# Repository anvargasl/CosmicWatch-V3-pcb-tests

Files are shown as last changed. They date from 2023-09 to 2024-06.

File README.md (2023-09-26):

# CosmicWatch_V3_RP

Handling versions of CosmicWatch pcb design, reusing V2 DC to DC booster and implementing new peak detection designa.

## CosmicWatch_detector_v30

main project, bringing together the different versions of parts desinged for peak detection and power.

### DC-DC-booster

Reimplementing CosmicWatch-V2 Dc to DC booster for lower noise in the power line.

### Peak-Detector

Latest peak detector circuit implemented for tests.

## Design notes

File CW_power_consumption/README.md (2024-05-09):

This folder contains some measurements made (current and tension) to test the power consumption of CosmicWatch while collecting data for gamma spectroscopy, all this while displaying data on the OLED screen, flashing the LED for every event, and recording temperature and preassure with the BMP280 sensor.

### CW_booting.csv

Power consumption data while initiating the detector.

### CW_high_count_rate.csv

Power consumption data while measuring a high count rate (next to a 54Mn source with 0.612 Mbq activity).

### CW_normal_working_conditions.csv

Power consumption data while measuring only background radiation from the enviroment and self-absorption of a 4x4x22 mm cubed LYSO crystal.

### CW_power_consumption.set

Contains the setup data for the Keithley Series 2280S High Precision Bench Power Supply used to measure current and tension.

### CW_power_measurements.txt

Shows some of the data collected by the CosmicWatch while testing its power consumption.

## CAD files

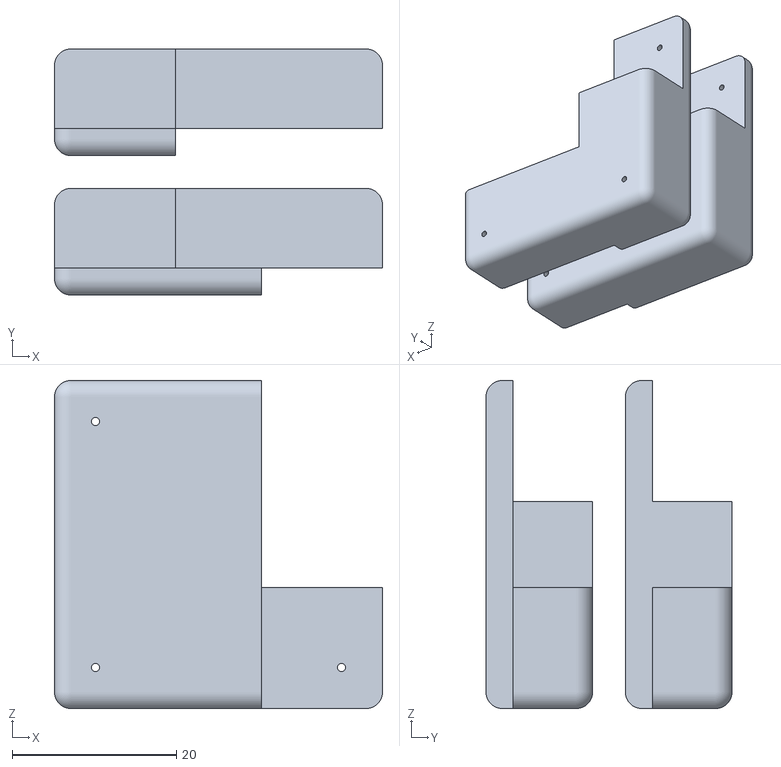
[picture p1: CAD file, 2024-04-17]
3D-print/BGO-10x10x10-holder.stl
40.0 x 30.0 x 40.0

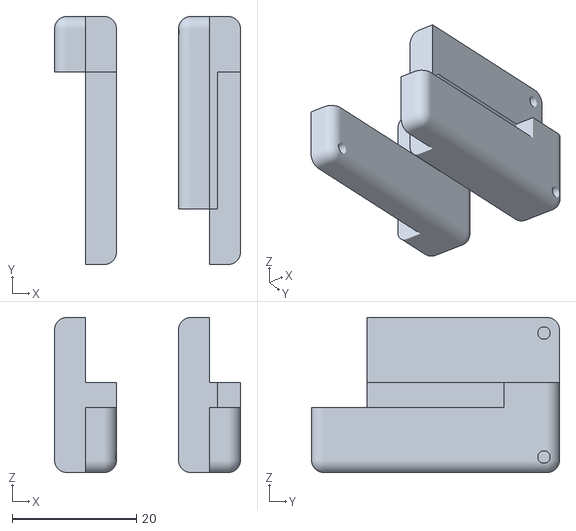
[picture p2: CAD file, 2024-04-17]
3D-print/LYSO-4x4x22-holder-T-pcb.stl
30.0 x 40.0 x 25.0

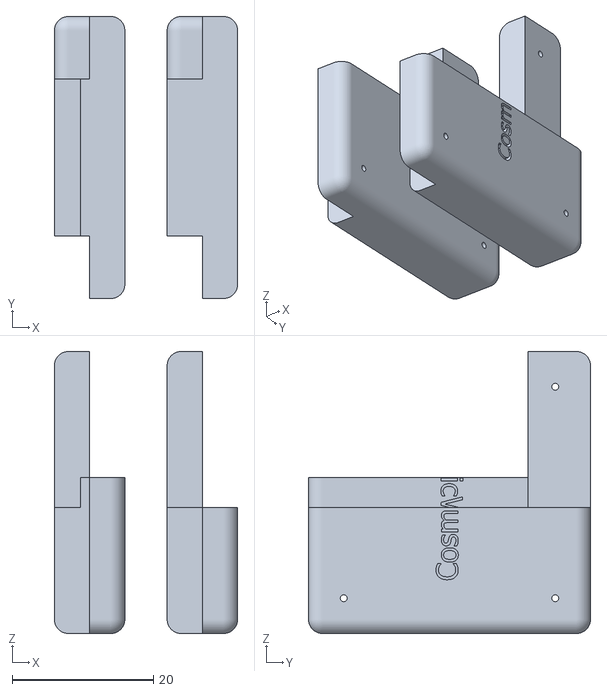
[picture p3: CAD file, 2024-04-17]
3D-print/LYSO-4x4x22-holder.stl
26.0 x 40.0 x 40.0

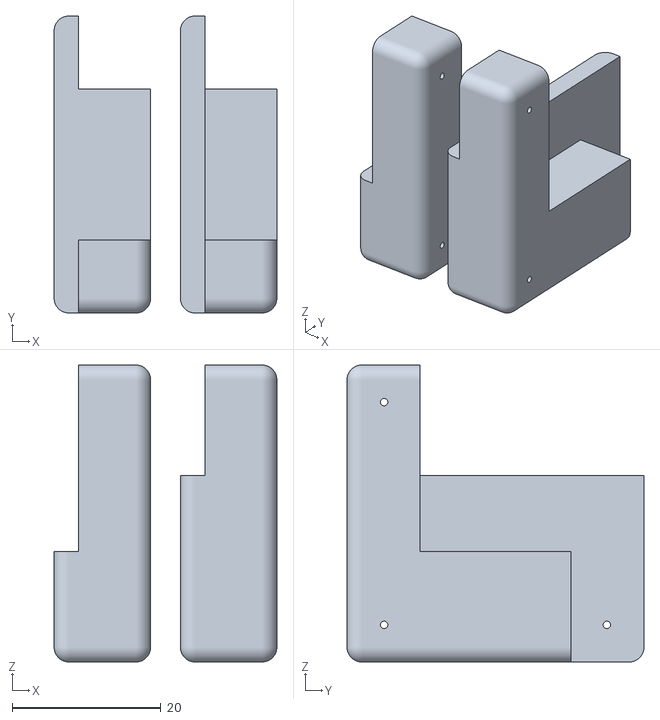
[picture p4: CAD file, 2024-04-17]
3D-print/BGO-10x10x20-holder.stl
30.0 x 40.0 x 40.0

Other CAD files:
3D-print/BGO-10x10x10-holder.ipt
3D-print/BGO-10x10x20-holder.ipt
3D-print/LYSO-4x4x22-holder-T-pcb.ipt
3D-print/LYSO-4x4x22-holder.ipt
3D-print/OldVersions/BGO-10x10x10-holder.0006.ipt
3D-print/OldVersions/BGO-10x10x20-holder.0004.ipt
3D-print/OldVersions/LYSO-4x4x22-holder-T-pcb.0002.ipt
3D-print/OldVersions/LYSO-4x4x22-holder.0024.ipt
3D-print/OldVersions/LYSO-holder-C-conector.0023.ipt
3D-print/OldVersions/LYSO-holder-V3.0001.ipt
3D-print/middle.ipt
3D-print/top-big.ipt
3D-print/top-small.ipt

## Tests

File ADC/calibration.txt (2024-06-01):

pulse_val,e_count,t0[us],dt0[us],readings
12,1,8297765,98,5425,5217,5425,5121,5537
12,2,8299051,91,5169,5569,5313,5089,5505
12,3,8300128,91,5217,5377,5313,5409,5473
12,4,8301174,88,5441,5073,5553,5281,5073
12,5,8302213,87,5185,5521,5377,5137,5569
12,6,8303245,92,5457,5089,5585,5313,5153
12,7,8304281,95,5361,5473,5169,5441,5121
12,8,8305327,92,5521,5105,5537,5377,5105
12,9,8306371,90,5345,5169,5457,5057,5425
12,10,8307419,89,5457,5089,5505,5377,5105
12,11,8308468,88,5329,5345,5105,5393,5553
12,12,8309514,92,5345,5297,5153,5505,5297
12,13,8316044,91,5409,4913,5393,5377,5025
12,14,8317162,88,5249,5377,5329,5073,5441
12,15,8318215,89,5537,5345,5025,5281,5537
12,16,8319274,87,5217,5329,5281,5185,5521
12,17,8320310,88,5073,5505,5377,5409,5313
12,18,8321342,87,5313,5377,5345,5281,5409
12,19,8322383,85,5505,5121,5313,5345,5265
12,20,8323415,85,5425,5025,5521,5281,5329
12,21,8324467,87,5345,5089,5537,5457,5009
12,22,8325507,87,5553,5137,5537,5441,5073
12,23,8326550,91,5473,5121,5553,5361,5121
12,24,8327579,88,5393,5089,5521,5217,5377
12,25,8334145,95,5329,5009,5425,5377,5089
12,26,8335256,88,5553,5025,5457,5361,4977
12,27,8336312,86,5441,5281,5313,5041,5393
12,28,8337352,86,5409,5009,5393,5297,4993
12,29,8338394,86,5169,5425,4993,5473,5137
12,30,8339427,92,5041,5553,5057,5393,5409
12,31,8340474,91,5537,5425,5217,5409,5201
12,32,8341520,88,5313,5265,5233,5377,5057
12,33,8342566,91,5393,5281,5313,5201,5425
12,34,8343604,89,5217,5377,5553,5009,5409
12,35,8344631,97,5089,5537,5169,5537,5345
12,36,8345696,87,5249,5297,5425,5153,5425
12,37,8352269,92,5441,5217,5105,5521,5153
12,38,8353378,92,5377,5201,5505,5041,5313
12,39,8354436,94,5201,5393,5073,5297,5345
12,40,8355483,87,5505,5041,5249,5649,5153
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

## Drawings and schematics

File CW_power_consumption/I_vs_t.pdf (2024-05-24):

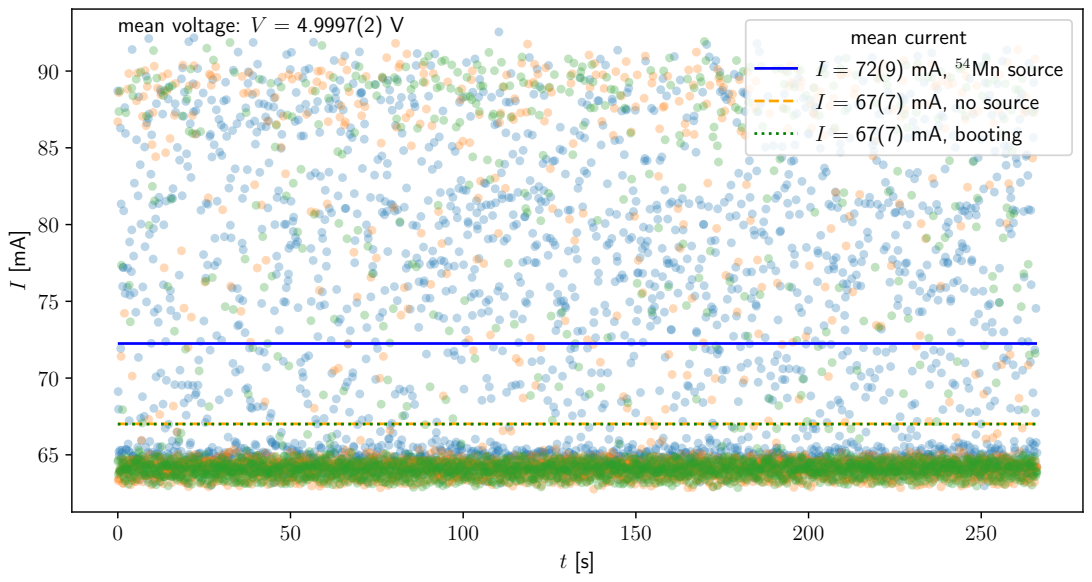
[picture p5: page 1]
mean voltage: V = 4.9997(2) V; mean current

I = 72(9) mA, 54Mn source
I = 67(7) mA, no source
I = 67(7) mA, booting

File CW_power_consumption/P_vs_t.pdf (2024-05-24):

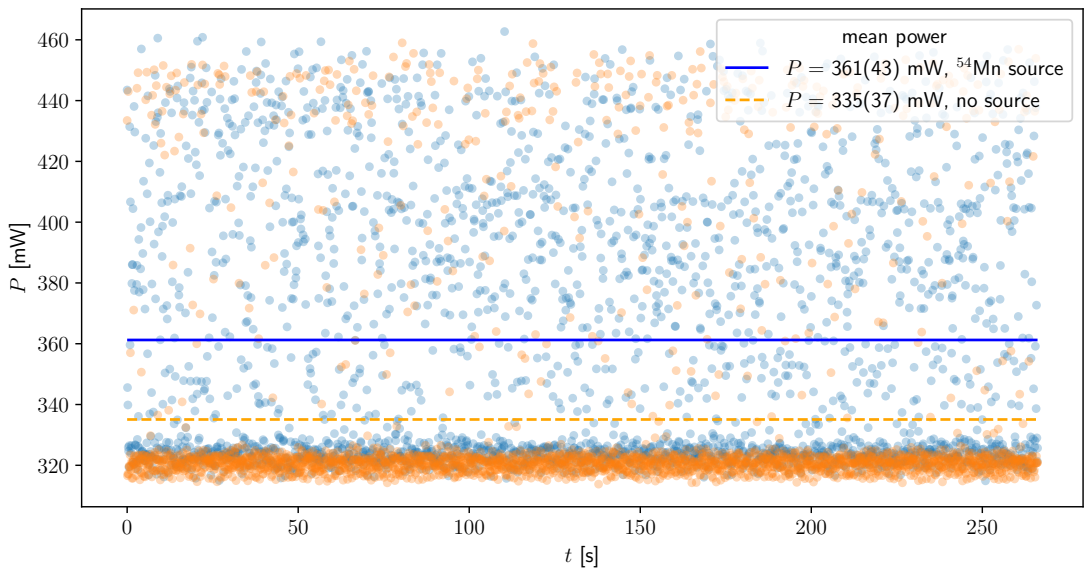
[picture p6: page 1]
mean power; = 361(43) mW, 54Mn source; = 335(37) mW, no source

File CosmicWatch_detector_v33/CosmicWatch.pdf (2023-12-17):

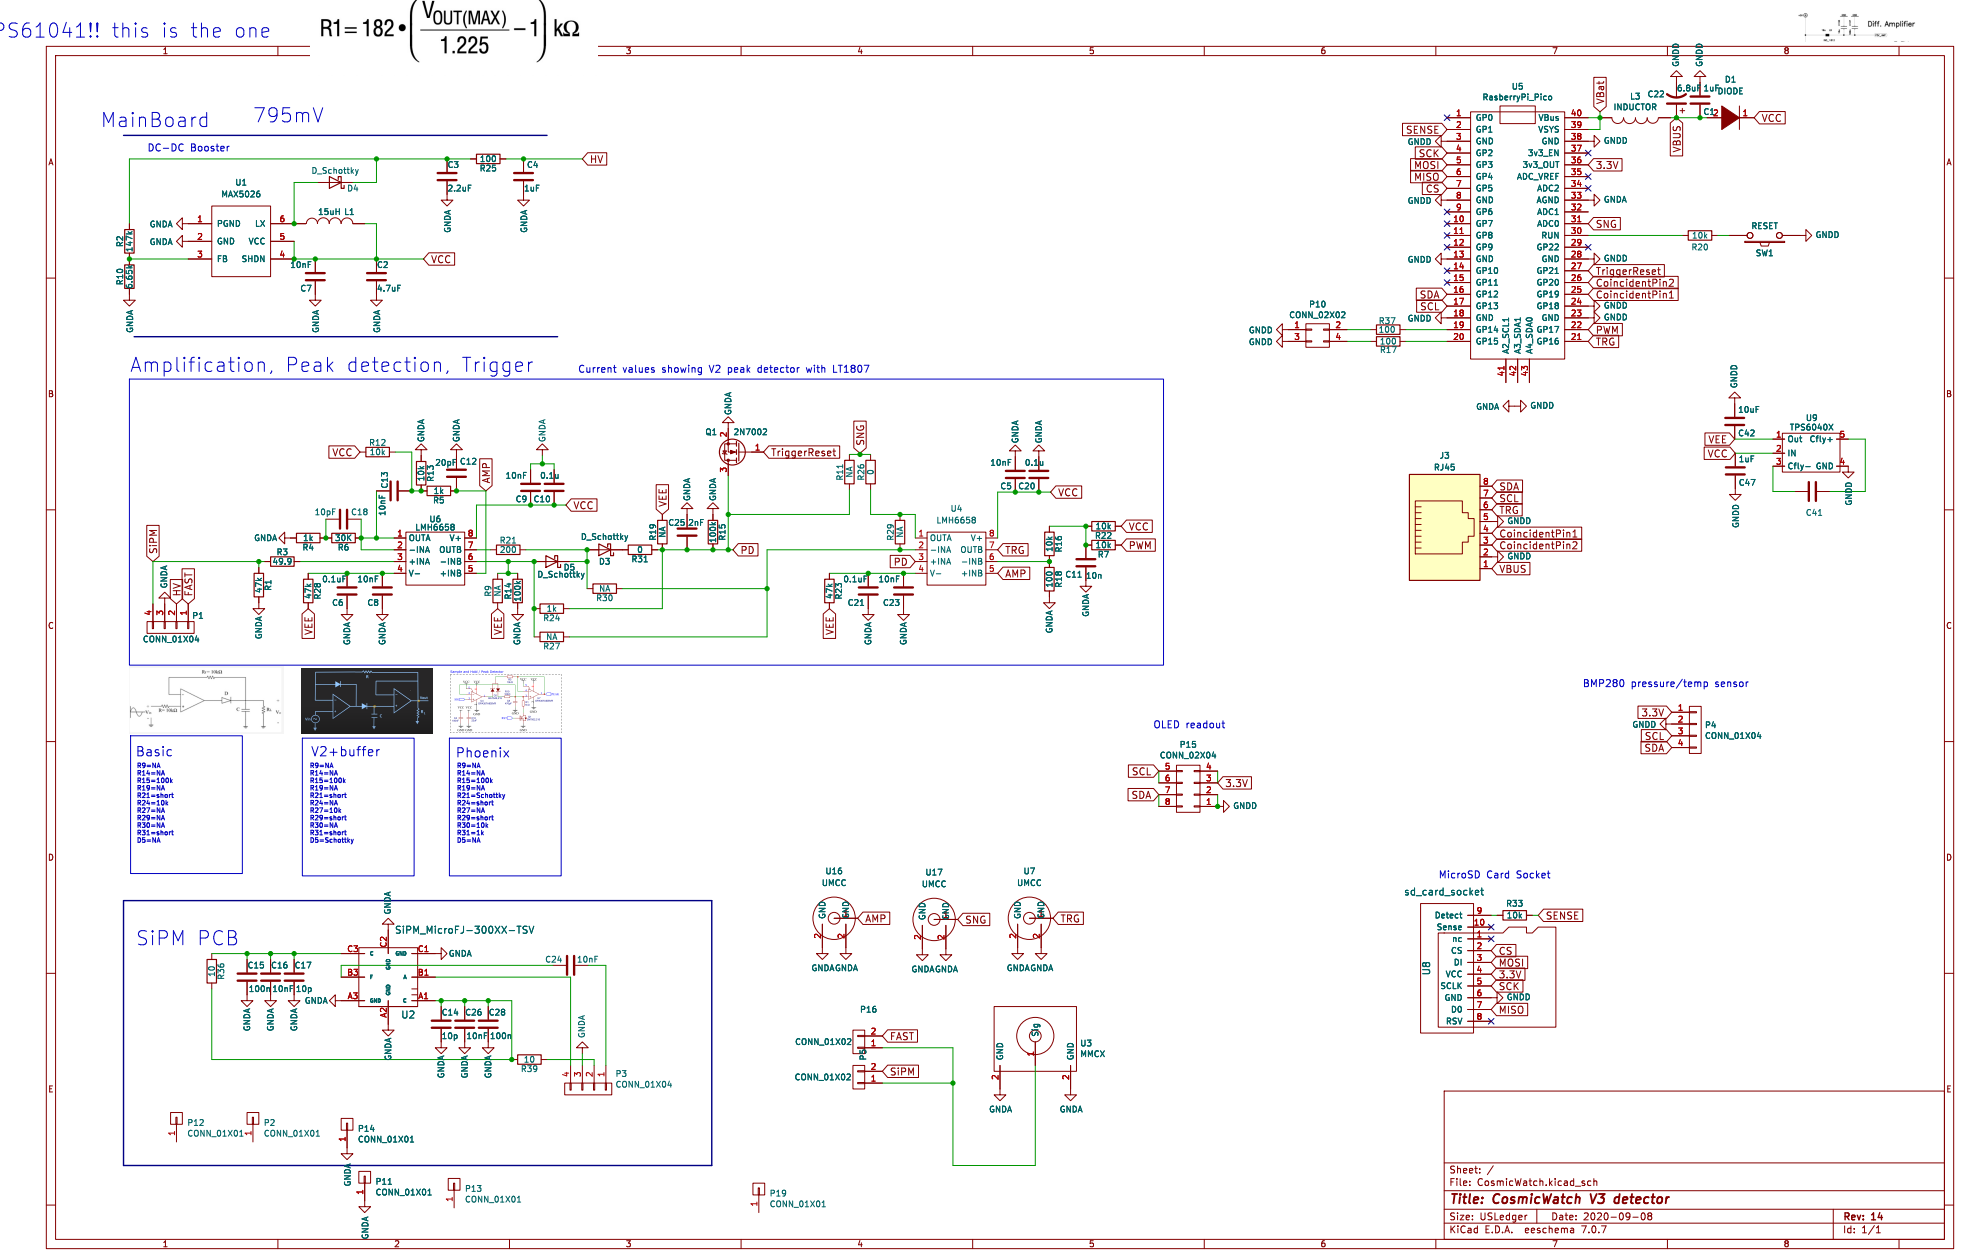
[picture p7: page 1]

1 P13 CONN_01X01 GNDA GNDA GNDA GNDA GNDA GNDA

2 U16 UMCC GNDA GNDA GNDA C7

R9=NA R14=NA R15=100k R19=NA R21=Schottky R24=short R27=NA R29=short R30=10k R31=1k D5=NA R9=NA R14=NA R15=100k R19=NA R21=short R24=NA R27=10k R29=short R30=NA R31=short D5=Schottky R9=NA R14=NA R15=100k R19=NA R21=short R24=10k R27=NA R29=NA R30=NA R31=short D5=NA Basic

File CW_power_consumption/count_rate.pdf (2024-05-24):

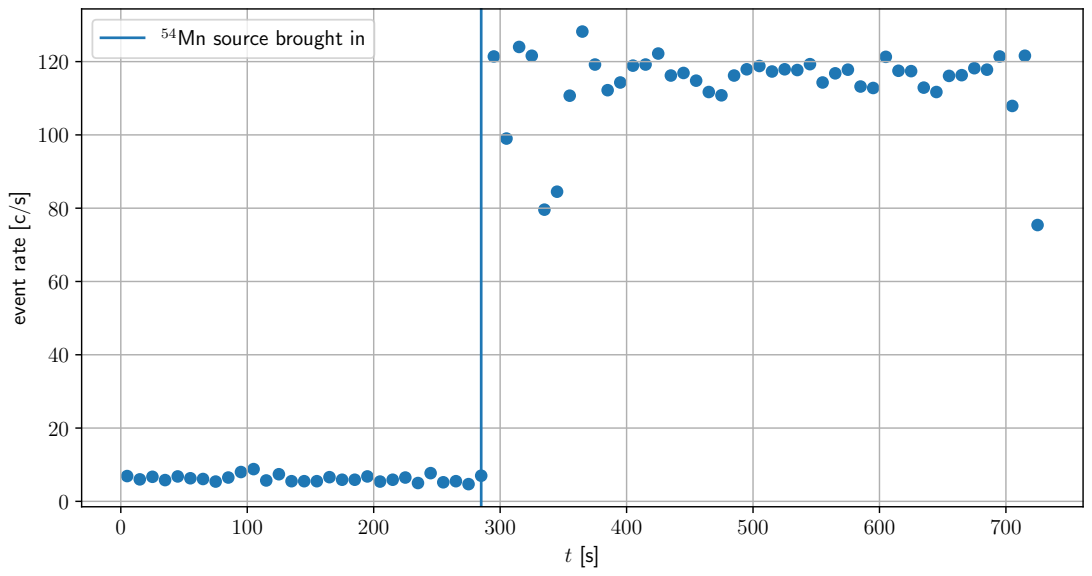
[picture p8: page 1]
event rate [c/s]

54Mn source brought in

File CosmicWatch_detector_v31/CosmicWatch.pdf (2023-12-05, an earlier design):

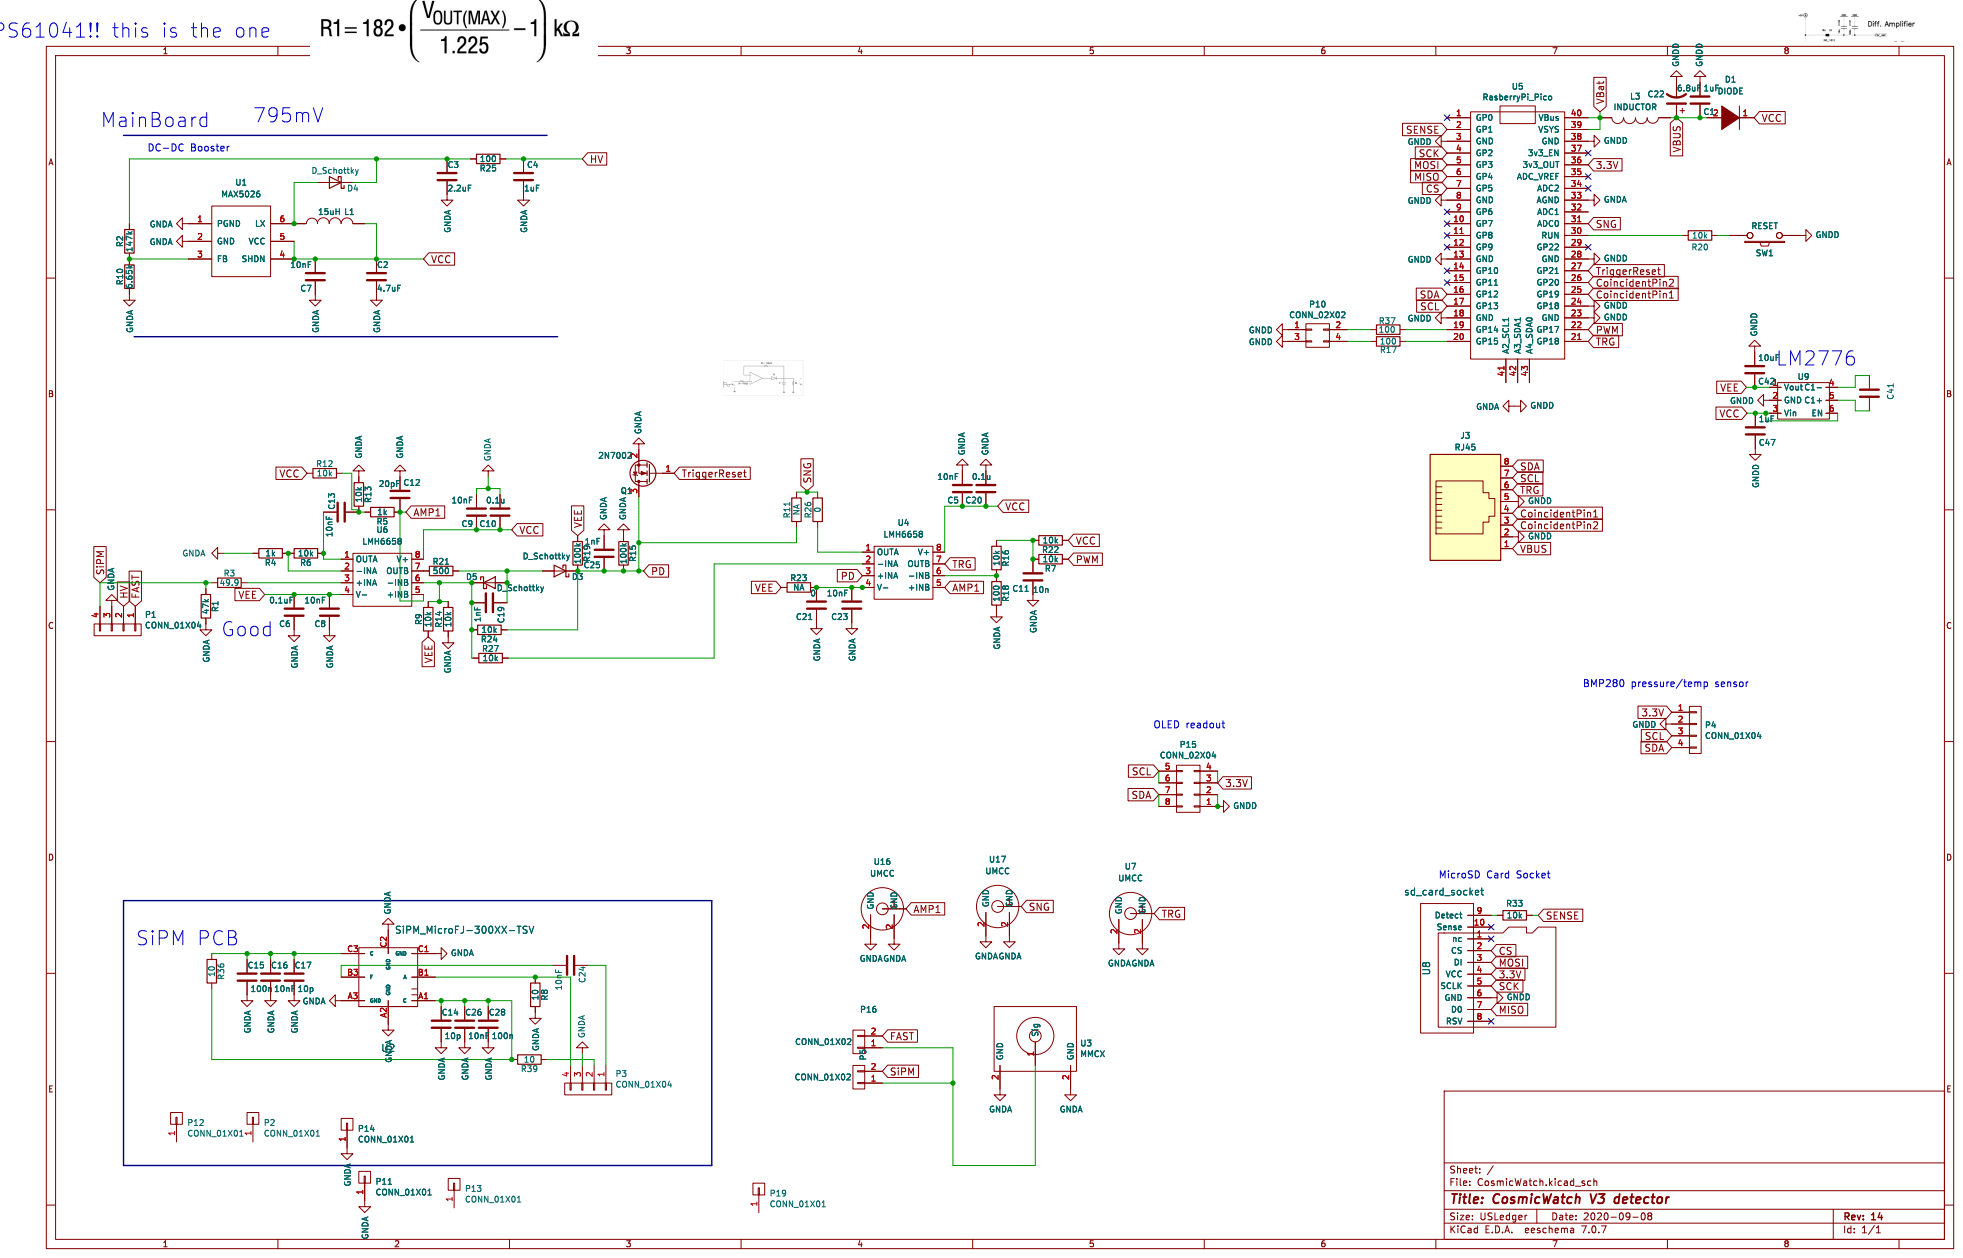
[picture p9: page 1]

OLED readout TPS61041!! this is the one

1P3CONN_01X04 C24 10nF GNDA R2 147k R10 6.65k GNDA GNDA GNDA

2 U16 UMCC GNDA GNDAGNDA Sig

2 GNDA GNDAGNDA U16 UMCC GND 1

Id: 1/1 Title: CosmicWatch V3 detector File: CosmicWatch.kicad_sch Sheet: /

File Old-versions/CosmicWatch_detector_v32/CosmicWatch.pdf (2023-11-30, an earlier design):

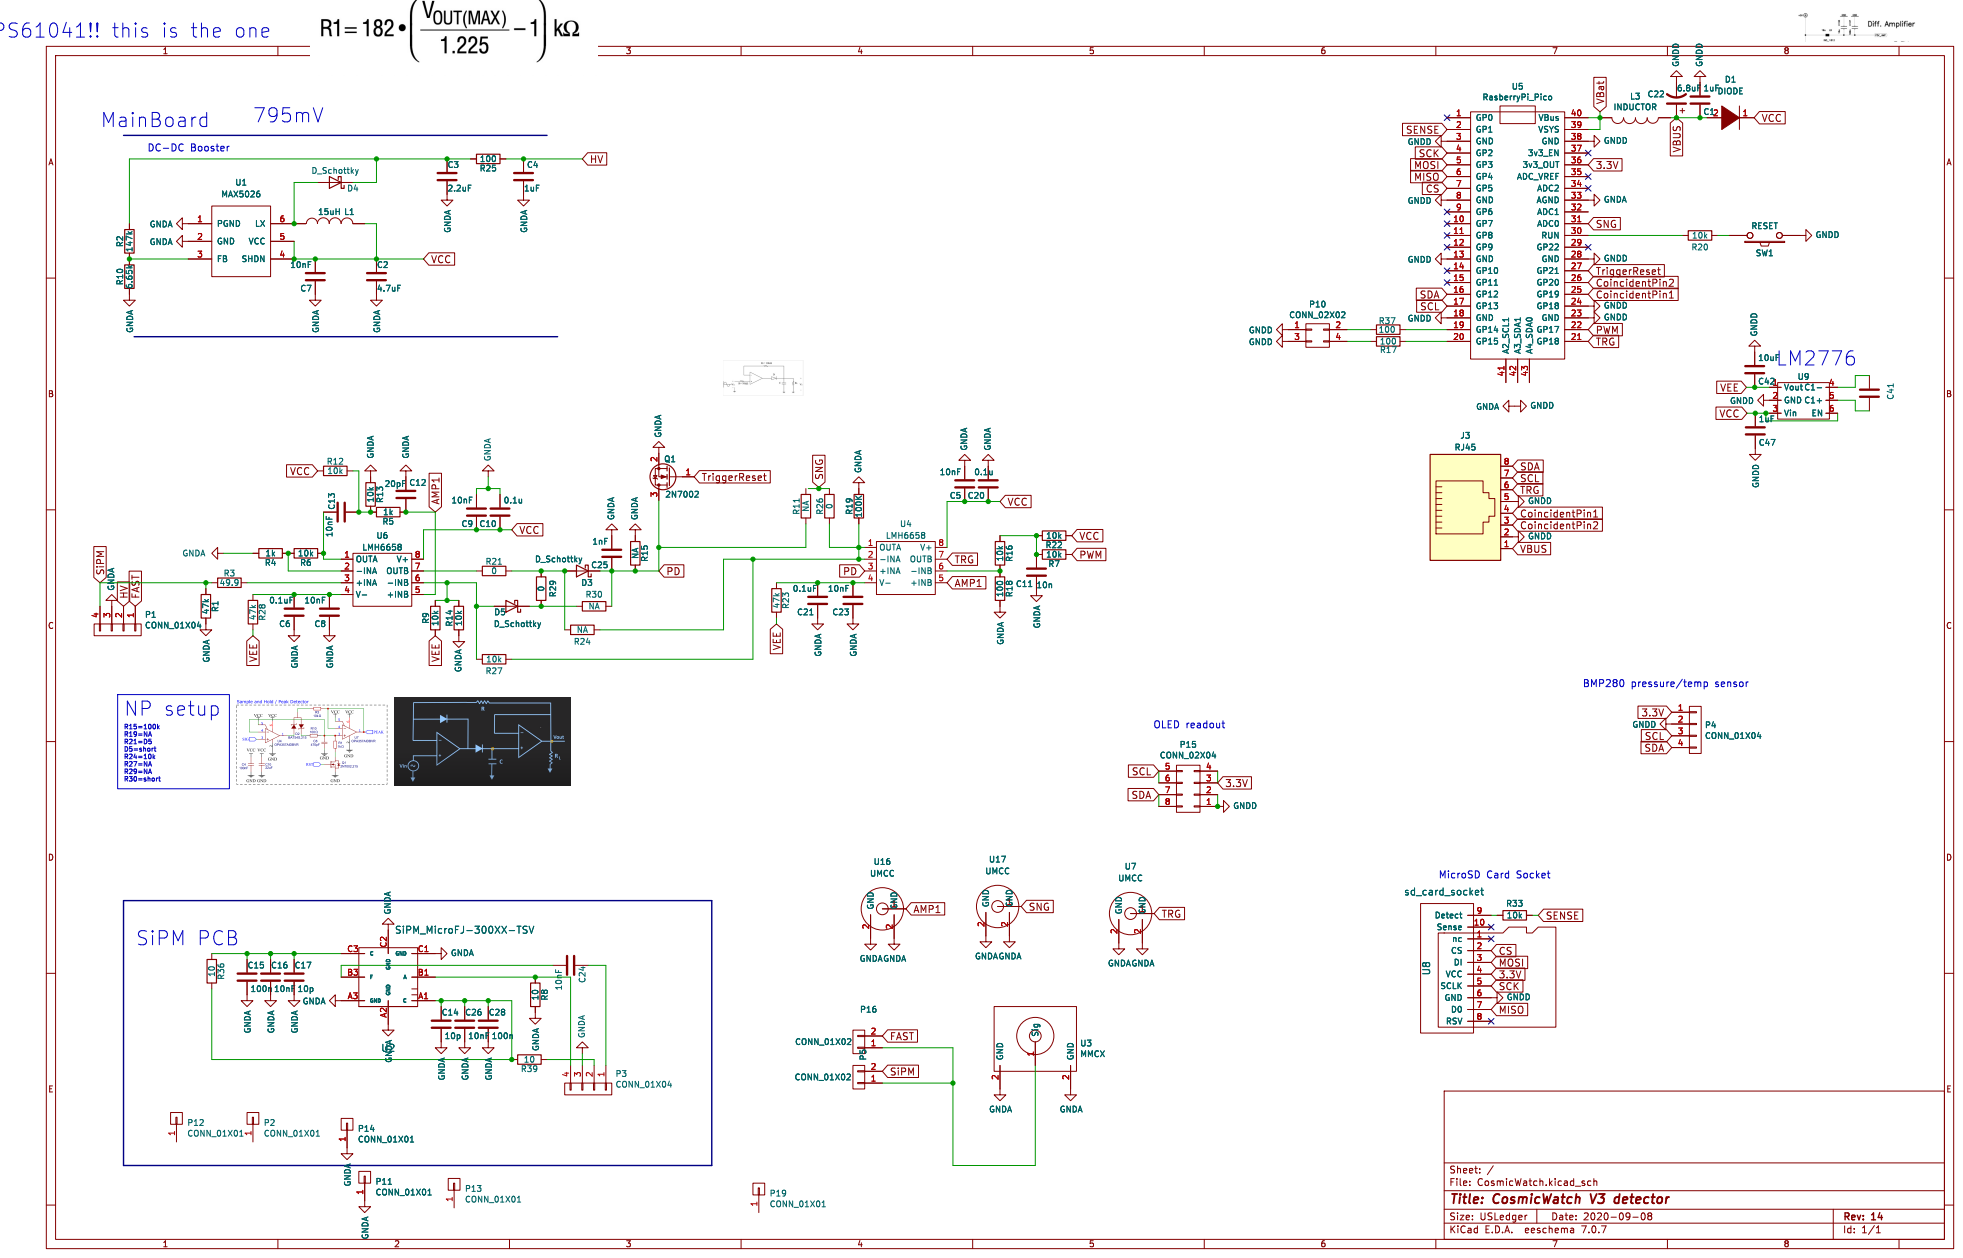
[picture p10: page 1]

TPS61041!! this is the one

1uF GNDD GNDD GNDD GNDD GNDD GNDD GNDD

1uF GNDD GNDD GNDD GNDD

1 P12 CONN_01X01 GNDA GNDA GNDA R10 6.65k R2 147k GNDA C7

R15=100k R19=NA R21=D5 D5=short R24=10k R27=NA R29=NA R30=short SiPM PCB

Id: 1/1 Title: CosmicWatch V3 detector File: CosmicWatch.kicad_sch Sheet: / GNDA R290

1 GNDA R14 10k GNDA GNDA GNDA R9 10k GNDA C15

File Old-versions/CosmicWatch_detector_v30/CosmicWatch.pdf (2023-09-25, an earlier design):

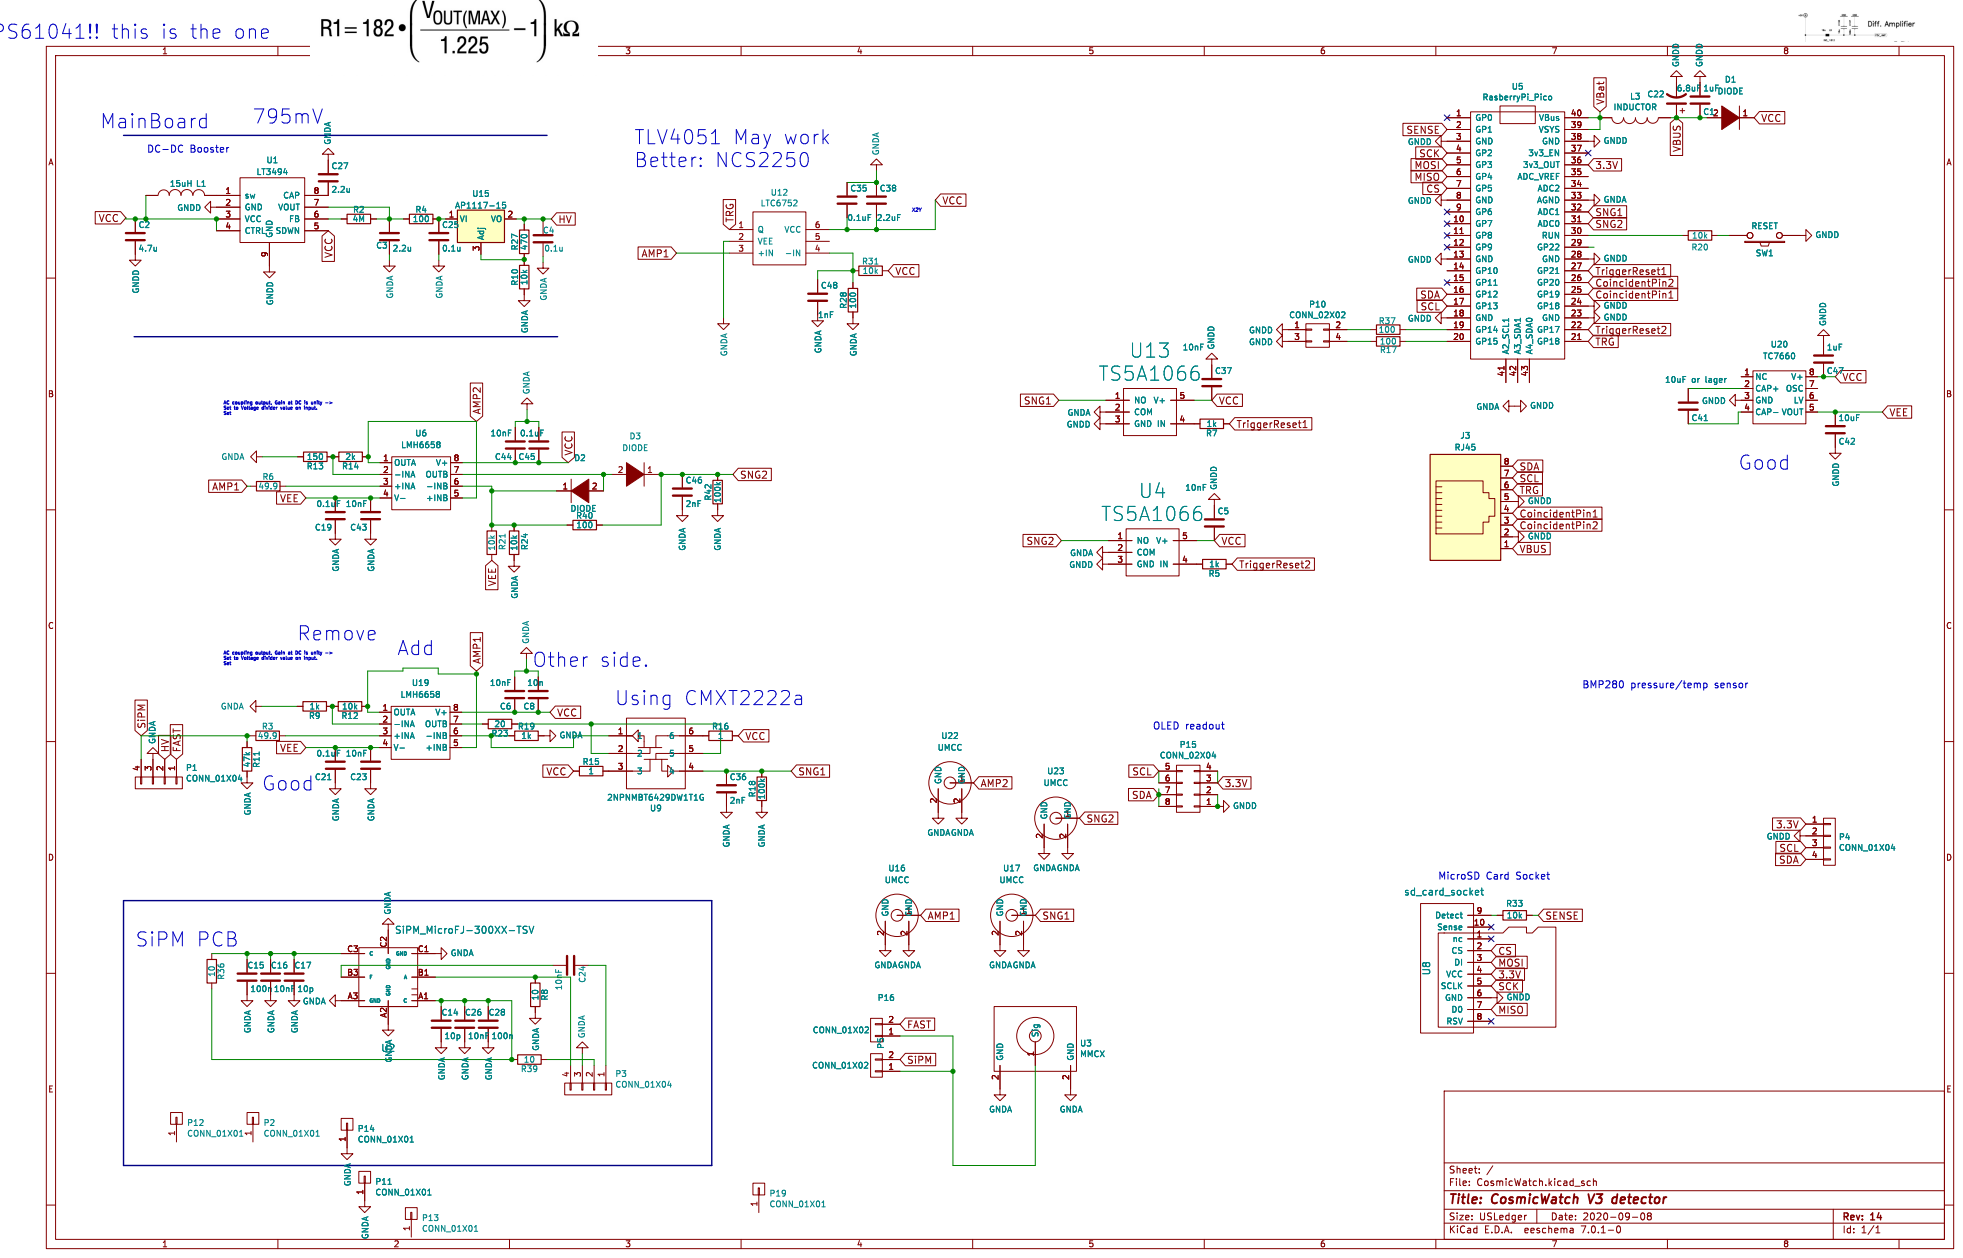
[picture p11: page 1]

OLED readout TPS61041!! this is the one

DC-DC Booster MainBoard

10uF or lager GNDD GNDA R42 100k GNDA C46

2 GNDAGNDA GNDAGNDA U22 UMCC GND 1

2 GNDA GNDAGNDA U16 UMCC GND 1

1 P14 CONN_01X01 GNDA 1 P13 CONN_01X01 GNDA 10R8 C24 10nF GNDA GNDA 4

Id: 1/1 Title: CosmicWatch V3 detector File: CosmicWatch.kicad_sch Sheet: /

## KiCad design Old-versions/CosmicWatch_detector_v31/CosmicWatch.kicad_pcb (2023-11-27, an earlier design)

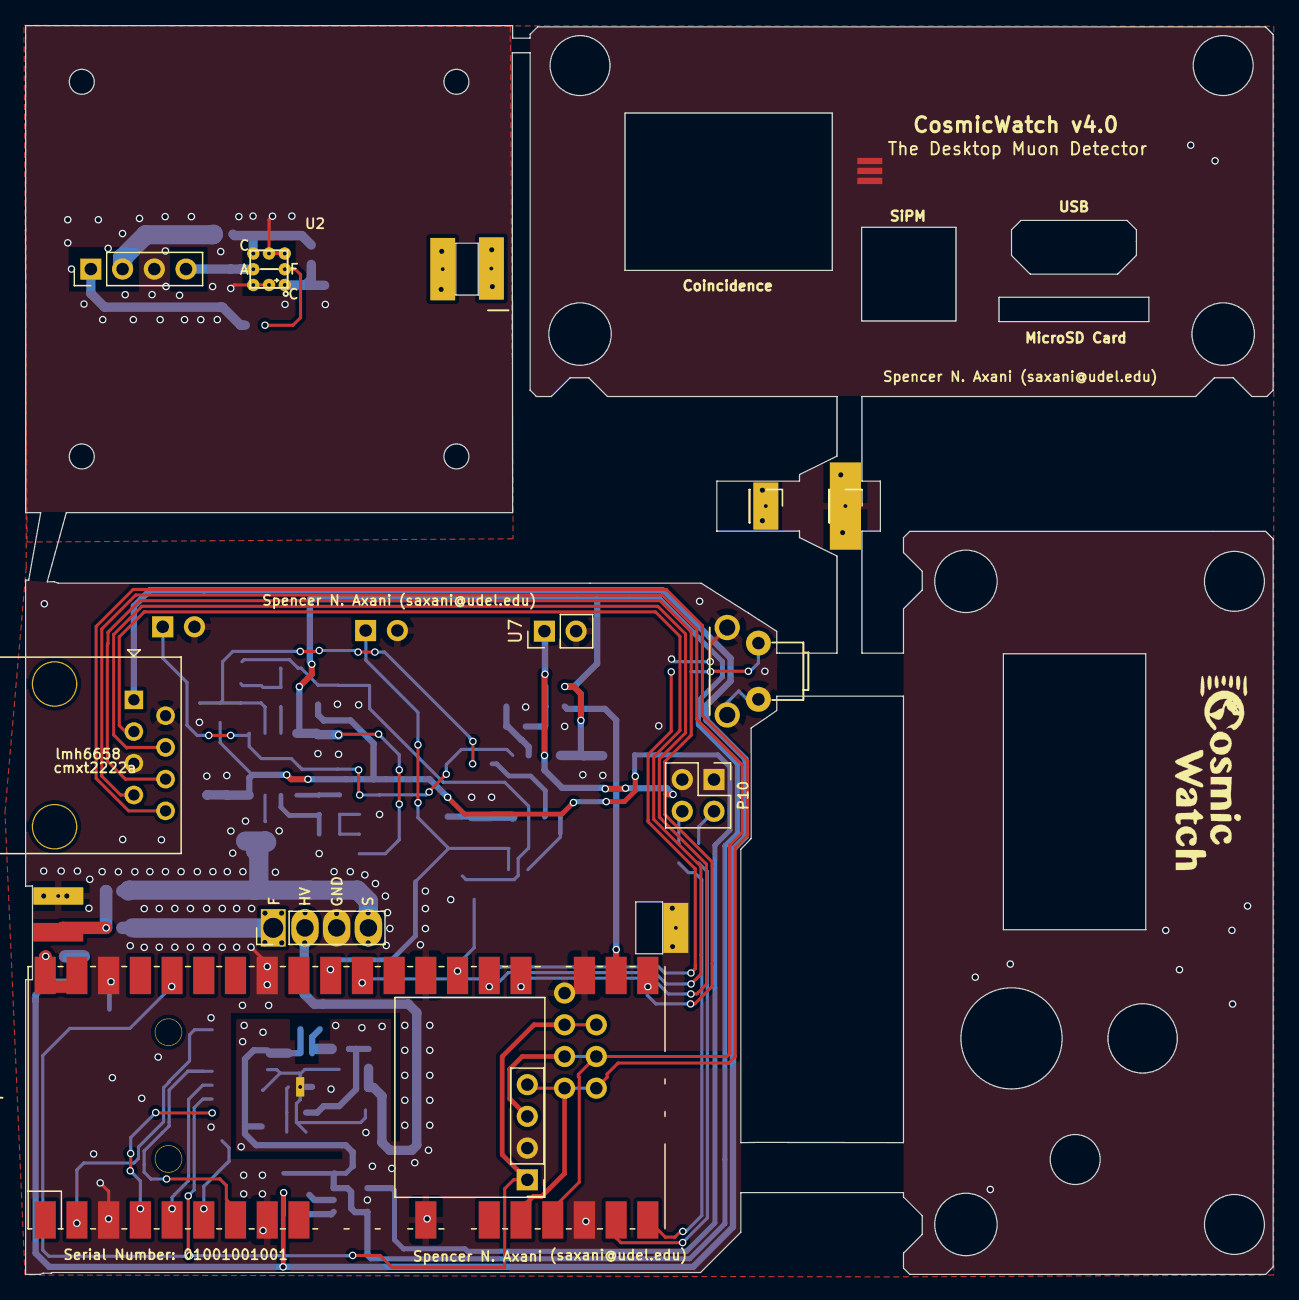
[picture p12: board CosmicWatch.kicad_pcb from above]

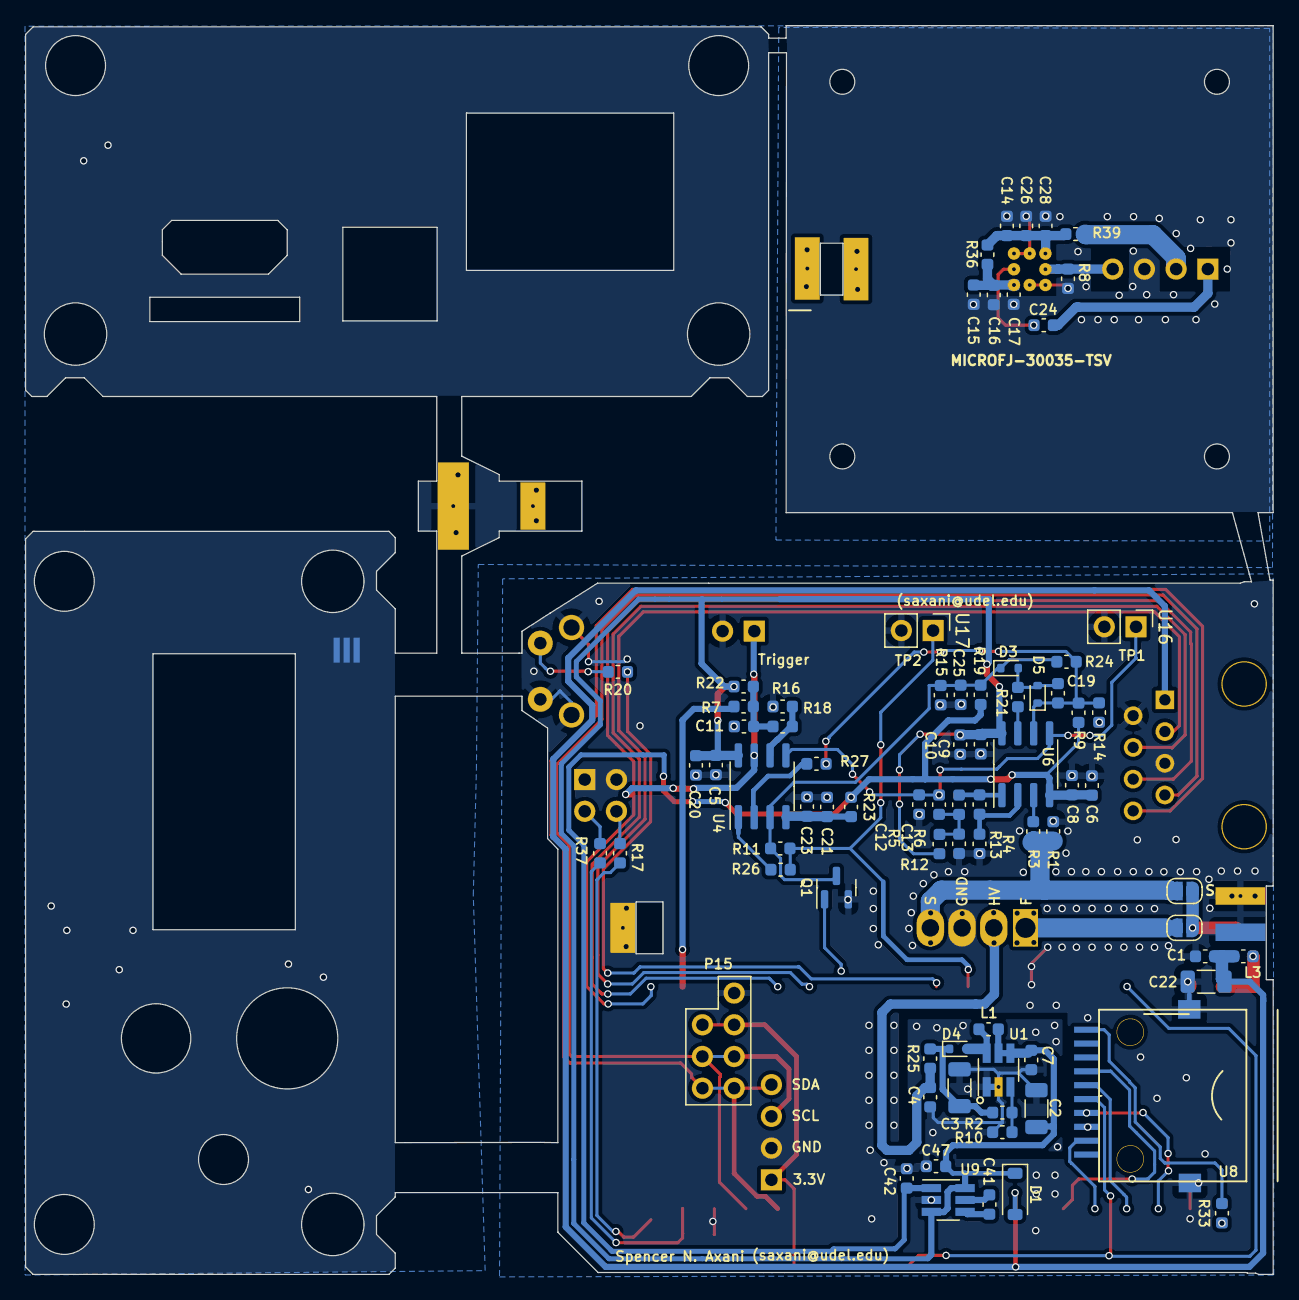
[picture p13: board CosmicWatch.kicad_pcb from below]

Board: 2 copper layers, 99.9 x 100.0 mm, 95 parts (79 on the bottom side), 55 nets.

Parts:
C1, C4, C47: 1uF; C_0603_1608Metric
C2: 4.7uF; C_1206_3216Metric
C3: 2.2uF; C_1206_3216Metric
C5, C7, C8, C9, C13, C16, C23, C24, C26: 10nF; C_0603_1608Metric
C6: 0.1uF; C_0603_1608Metric
C10, C20: 0.1u; C_0603_1608Metric
C11: 10n; C_0603_1608Metric
C12: 20pF; C_0603_1608Metric
C14, C17: 10p; C_0603_1608Metric
C15, C28: 100n; C_0603_1608Metric
C19, C25: 1nF; C_0603_1608Metric
C21: 0; C_0603_1608Metric
C22: 6.8uF; C_1206_3216Metric
C41: C_0603_1608Metric
C42: 10uF; C_0603_1608Metric
D1: DIODE; D_SOD-123
D3, D4, D5: D_Schottky; D_SOD-523
J3: RJ45; RJ45_OST_PJ012-8P8CX_Vertical
L1: 15uH; C_0603_1608Metric
L3: INDUCTOR; C_0603_1608Metric
P1: CONN_01X04; PinHeader4_bigger_SiPM
P2: CONN_01X01; SiPM_PCB_Standoff
P3, P4: CONN_01X04; PinHeader_1x04_P2.54mm_Vertical
P5, P16: CONN_01X02; SolderJumper-2_P1.3mm_Open_RoundedPad1.0x1.5mm
P7, P8: CONN_01X01; GND_circle
P10: CONN_02X02; PinHeader_2x02_P2.54mm_Vertical
P11, P12, P13, P14: CONN_01X01; PinHeader_1x01_P2.54mm_Vertical
P15: CONN_02X04; PinHeader_2x04_P2.54mm_Vertical
P19: CONN_01X01; logo
Q1: 2N7002; SOT-23
R1: 47k; C_0603_1608Metric
R2: 147k; C_0603_1608Metric
R3: 49.9; C_0603_1608Metric
R4, R5: 1k; C_0603_1608Metric
R6, R7, R9, R12, R13, R14, R16, R20, R22, R24, R27, R33: 10k; C_0603_1608Metric
R8, R36, R39: 10; C_0603_1608Metric
R10: 6.65k; C_0603_1608Metric
R11, R23: NA; C_0603_1608Metric
R15, R19: 100k; C_0603_1608Metric
R17, R18, R25, R37: 100; C_0603_1608Metric
R21: 500; C_0603_1608Metric
R26: 0; C_0603_1608Metric
SW1: RESET; reset_button
U1: MAX5026; SOT-23-6_Handsoldering
U2: SiPM_MicroFJ−300XX−TSV
U3: MMCX; SMA_side_mount_sideways
U4, U6: LMH6658; SOIC-8_3.9x4.9mm_P1.27mm
U5: RasberryPi_Pico; RPi_Pico_SMD_TH_noThroughHoles
U7, U16, U17: UMCC; PinHeader_1x02_P2.54mm_Vertical
U8: sd_card_socket; sd_card
U9: SOT-23-6_Handsoldering

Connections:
3.3V: P4.1, P15.3, P15.4, U5.36 (3v3_OUT), U8.4 (VCC)
AMP1: C12.2, R5.1, U4.5 (+INB), U6.5 (+INB), U16.1
CS: U5.7 (GP5), U8.2 (CS)
CoincidentPin1: J3.4, U5.25 (GP19)
CoincidentPin2: J3.3, U5.26 (GP20)
FAST: P1.1, P16.2
GNDA: C1.2, C2.2, C3.2, C4.2, C5.2, C6.1, C7.1, C8.1, C9.2, C10.2, C11.1, C12.1, C14.2, C15.2, C16.2, C17.2, C20.2, C21.1, C22.2, C23.1, C25.2, C26.2, C28.2, C42.2, C47.1, J3.2, J3.5, P1.3, P3.3, P4.2, P7.1, P8.1, P10.1, P10.3, P11.1, P14.1, P15.2, Q1.2 (S), R1.2, R4.2, R8.2, R10.1, R13.1, R14.1, R15.1, R18.2, SW1.1, U1.1 (PGND), U1.2 (GND), U2.A2 (GND), U2.A3 (GND), U2.C1 (GND), U2.C2 (GND), U3.2 (GND), U5.3 (GND), U5.8 (GND), U5.13 (GND), U5.18 (GND), U5.23 (GND), U5.28 (GND), U5.33 (AGND), U5.38 (GND), U7.2 (GND), U8.6 (GND), U9.2 (GND), U16.2 (GND), U17.2 (GND)
HV: C4.1, P1.2, R25.1
MISO: U5.6 (GP4), U8.7 (D0)
MOSI: U5.5 (GP3), U8.3 (DI)
unnamed: C11.2, R7.2, R16.1, R22.2
unnamed: C13.1, R5.2, R12.2, R13.2
unnamed: C14.1, C26.1, C28.1, R36.2, R39.2, U2.A1 (C)
unnamed: C15.1, C16.1, C17.1, R36.1, U2.C3 (C)
unnamed: C19.1, D3.2 (A), D5.2 (A), R21.2
unnamed: D4.2 (A), L1.1, U1.6 (LX)
unnamed: C3.1, D4.1 (K), R2.2, R25.2
unnamed: C19.2, D5.1 (K), R9.2, R14.2, R24.2, R27.1, U6.6 (-INB)
unnamed: C24.1, P3.1
unnamed: P3.2, R39.1
unnamed: P3.4, R8.1, U2.B1 (A)
unnamed: P10.2, R37.1
unnamed: P10.4, R17.2
unnamed: P5.1, P16.1, U3.1 (Sig)
unnamed: R20.2, SW1.2
unnamed: R2.1, R10.2, U1.3 (FB)
unnamed: C24.2, U2.B3 (F)
unnamed: R27.2, U4.2 (-INA)
unnamed: R16.2, R18.1, U4.6 (-INB)
unnamed: R26.1, U4.1 (OUTA)
unnamed: C21.2, C23.2, R23.2, U4.4 (V-)
unnamed: R37.2, U5.19 (GP14)
unnamed: R17.1, U5.20 (GP15)
unnamed: R20.1, U5.30 (RUN)
unnamed: R3.2, U6.3 (+INA)
unnamed: R4.1, R6.2, U6.2 (-INA)
unnamed: C13.2, R6.1, U6.1 (OUTA)
unnamed: R21.1, U6.7 (OUTB)
unnamed: R33.2, U8.9 (Detect)
unnamed: C41.2, U9.5 (C1+)
unnamed: C41.1, U9.4 (C1-)
PD: C25.1, D3.1 (K), Q1.3 (D), R11.1, R15.2, R19.2, R24.1, U4.3 (+INA)
PWM: R7.1, U5.22 (GP17)
SCK: U5.4 (GP2), U8.5 (SCLK)
SCL: J3.7, P4.3, P15.5, P15.6, U5.17 (GP13)
SDA: J3.8, P4.4, P15.7, P15.8, U5.16 (GP12)
SENSE: R33.1, U5.2 (GP1)
SNG: R11.2, R26.2, U5.31 (ADC0), U17.1
SiPM: P1.4, P5.2, R1.1, R3.1
TRG: J3.6, U4.7 (OUTB), U5.21 (GP18), U7.1
TriggerReset: Q1.1 (G), U5.27 (GP21)
VBUS: C1.1, C22.1, D1.2 (K), J3.1, L3.1
VBat: L3.2, U5.39 (VSYS), U5.40 (VBus)
VCC: C2.1, C5.1, C7.2, C9.1, C10.1, C20.1, C47.2, D1.1 (A), L1.2, R12.1, R22.1, U1.4 (SHDN), U1.5 (VCC), U4.8 (V+), U6.8 (V+), U9.3 (Vin), U9.6 (EN)
VEE: C6.2, C8.2, C42.1, R9.1, R19.1, R23.1, U6.4 (V-), U9.1 (Vout)

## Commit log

2023-09-25 adding DC-DC booster on v3 schematics and pcb
    [CosmicWatch.kicad_pcb, CosmicWatch.kicad_sch]
2023-09-25 fixing misplaced VCC conection
    [CosmicWatch.kicad_pcb]
2023-09-26 adding peak detector sketch, deleting misplaced folder
    [DC-DC-booster.kicad_sch, Peak-Detector.kicad_pcb, Peak-Detector.kicad_sch]
2023-09-26 adding new peak detector schematic
    [Peak-Detector.kicad_sch]
2023-09-27 rearranging DC-DC booster components
    [CosmicWatch.kicad_pcb, CosmicWatch.kicad_sch]
2023-09-30 adding Nuclear-Phoenix-inspired peak detector schematic
    [Peak-Detector.kicad_sch]
2023-10-02 new booster added
    [CosmicWatch.kicad_pcb, CosmicWatch.kicad_sch]
2023-10-02 removing second sipm
    [CosmicWatch.kicad_pcb, CosmicWatch.kicad_sch]
2023-10-02 adding peak detector and comparator
    [CosmicWatch.kicad_sch, Peak-Detector.kicad_sch]
2023-10-02 fixing R13 resistance value
    [CosmicWatch.kicad_sch]
2023-10-03 removig old comparator
    [CosmicWatch.kicad_sch]
2023-10-03 moved MOSFET
    [CosmicWatch.kicad_sch]
2023-10-05 updating netlist and deleting unnecessary components from PCB
    [CosmicWatch.kicad_pcb, CosmicWatch.kicad_sch]
2023-10-05 rearranging peak detector in pcb
    [CosmicWatch.kicad_pcb]
2023-10-06 placing peak detector
    [CosmicWatch.kicad_pcb]
2023-10-08 finished peak detector placin and wiring, starting error corrections
    [CosmicWatch.kicad_pcb]
2023-10-16 fixed errors, resized SiPM pcb
    [CosmicWatch.kicad_pcb]
2023-10-17 adding some changes
    [CosmicWatch.kicad_pcb]
2023-10-17 added R5 on trigger reset
    [CosmicWatch.kicad_pcb, CosmicWatch.kicad_sch]
2023-11-06 adding old peak detetion schematic
    [CosmicWatch.kicad_sch, Peak-Detector.kicad_sch]
2023-11-20 optimizing some components
    [CosmicWatch.kicad_sch, Peak-Detector.kicad_sch]
2023-11-27 adding update
    [CosmicWatch-B_Cu.gbr, CosmicWatch-B_Mask.gbr, CosmicWatch-B_Silkscreen.gbr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]
2023-11-30 New PCB design to test LT1807 with NPhoenix and CW V2 PD
    [CosmicWatch-B_Cu.gbr, CosmicWatch-B_Mask.gbr, CosmicWatch-B_Silkscreen.gbr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]
2023-11-30 updating schematic pdf
    [CosmicWatch.kicad_sch]
2023-11-30 updating pcb
    [CosmicWatch.kicad_pcb, CosmicWatch.kicad_sch]
2023-12-05 updating CW v31 schematic pdf
2023-12-17 going back to TPS6040 for VEE, erasing unnecessary features from schematic
    [CosmicWatch-B_Cu.gbr, CosmicWatch-B_Mask.gbr, CosmicWatch-B_Silkscreen.gbr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]
2023-12-19 fixing some component values
    [CosmicWatch.kicad_sch]
2023-12-19 deleting unnecessary folders
    [DC-DC-booster.kicad_pcb, DC-DC-booster.kicad_sch, Peak-Detector.kicad_pcb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]
2023-12-19 rearranging old versions
    [CosmicWatch-B_Cu.gbr, CosmicWatch-B_Mask.gbr, CosmicWatch-B_Silkscreen.gbr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]
2024-04-17 adding 3D printed case files
    [BGO-10x10x10-holder.0006.ipt, BGO-10x10x10-holder.ipt, BGO-10x10x10-holder.stl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]
2024-05-09 adding power consumptioon data
    [CW_booting.csv, CW_high_count_rate.csv, CW_normal_working_conditions.csv]
2024-05-16 added power consumption and count rate plot and scripts
2024-05-16 adding power consumption and count rate plots
    [CW_booting.csv, CW_high_count_rate.csv, CW_normal_working_conditions.csv]
2024-06-01 adding some adc calibration measurements
2024-06-05 adding code for ADC-voltage calibration
